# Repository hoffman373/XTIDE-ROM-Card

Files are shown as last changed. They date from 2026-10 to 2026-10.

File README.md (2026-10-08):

# XTIDE-ROM-Card

An 8-bit ISA card that holds a 27C256 EPROM as an option ROM in the upper memory area of a PC/XT-class machine, typically to load the [XTIDE Universal BIOS](https://www.xtideuniversalbios.org/).

The schematic is a redraw of Dan Hoover's "The $4 XTIDE" concept.

## Overview

- **ROM:** 27C256 (32 KB) EPROM in a 28-pin DIP socket
- **Address decode:** 74LS688 8-bit comparator in a 20-pin DIP socket
- **Address select:** 2x4 pin header (J1) with a SIP-5 pull-up resistor network (RN1)
- **Bus connector:** 8-bit ISA edge connector (`Bus_ISA_8bit`)
- **Decoupling:** 100 nF disc capacitors on each IC

### How it works

The 74LS688 compares A19-A15 against the levels set on J1. It also requires AEN low (no DMA cycle) and /MEMR low (memory read). When everything matches, it pulls `ROM_SEL` low and the EPROM drives D0-D7 for the read.

A19 is tied to match 1, so the 32 KB window always falls between 80000h and FFFFFh. RN1 pulls `SEL_A15` to `SEL_A18` high. Installing a jumper pulls that bit low.

### Address selection

| J1 pins | Address bit |
|---|---|
| 1-2 | A15 |
| 3-4 | A16 |
| 5-6 | A17 |
| 7-8 | A18 |

Jumper **in** = 0, jumper **out** = 1.

| ROM base | A18 | A17 | A16 | A15 | Jumpers installed |
|---|---|---|---|---|---|
| C8000h | 1 | 0 | 0 | 1 | 3-4, 5-6 |
| D0000h | 1 | 0 | 1 | 0 | 1-2, 5-6 |
| D8000h | 1 | 0 | 1 | 1 | 5-6 |
| E0000h | 1 | 1 | 0 | 0 | 1-2, 3-4 |
| E8000h | 1 | 1 | 0 | 1 | 3-4 |

- Keep the jumper off 7-8. A18 = 0 maps the ROM into A0000h-BFFFFh, which is video memory.
- C0000h is normally taken by the video BIOS.
- Pick a window that doesn't overlap video memory, a hard disk controller BIOS, or any other option ROM in the machine.

## Opening the project

1. Install [KiCad](https://www.kicad.org/) 10 or newer. The files use the KiCad 10 format and will not open in older versions.
2. Clone the repository:
   ```
   git clone https://github.com/hoffman373/XTIDE-ROM-Card.git
   ```
3. Open `xtide_rom_card.kicad_pro`.

Custom footprints live in `lib/footprints/` and are registered through the project's `fp-lib-table` using `${KIPRJMOD}`, so no library setup is needed. Everything else uses stock KiCad symbols and footprints.

## Programming the ROM

Burn the ROM image (for example, an XTIDE Universal BIOS build configured for your controller) to a 27C256 with any EPROM programmer. If the image is smaller than 32 KB, pad it to 32 KB with `FFh`. The BIOS checksum must be valid or the system BIOS will skip the ROM during its option ROM scan.

## License

CC BY-SA 4.0, share-alike with the original $4 XTIDE design.

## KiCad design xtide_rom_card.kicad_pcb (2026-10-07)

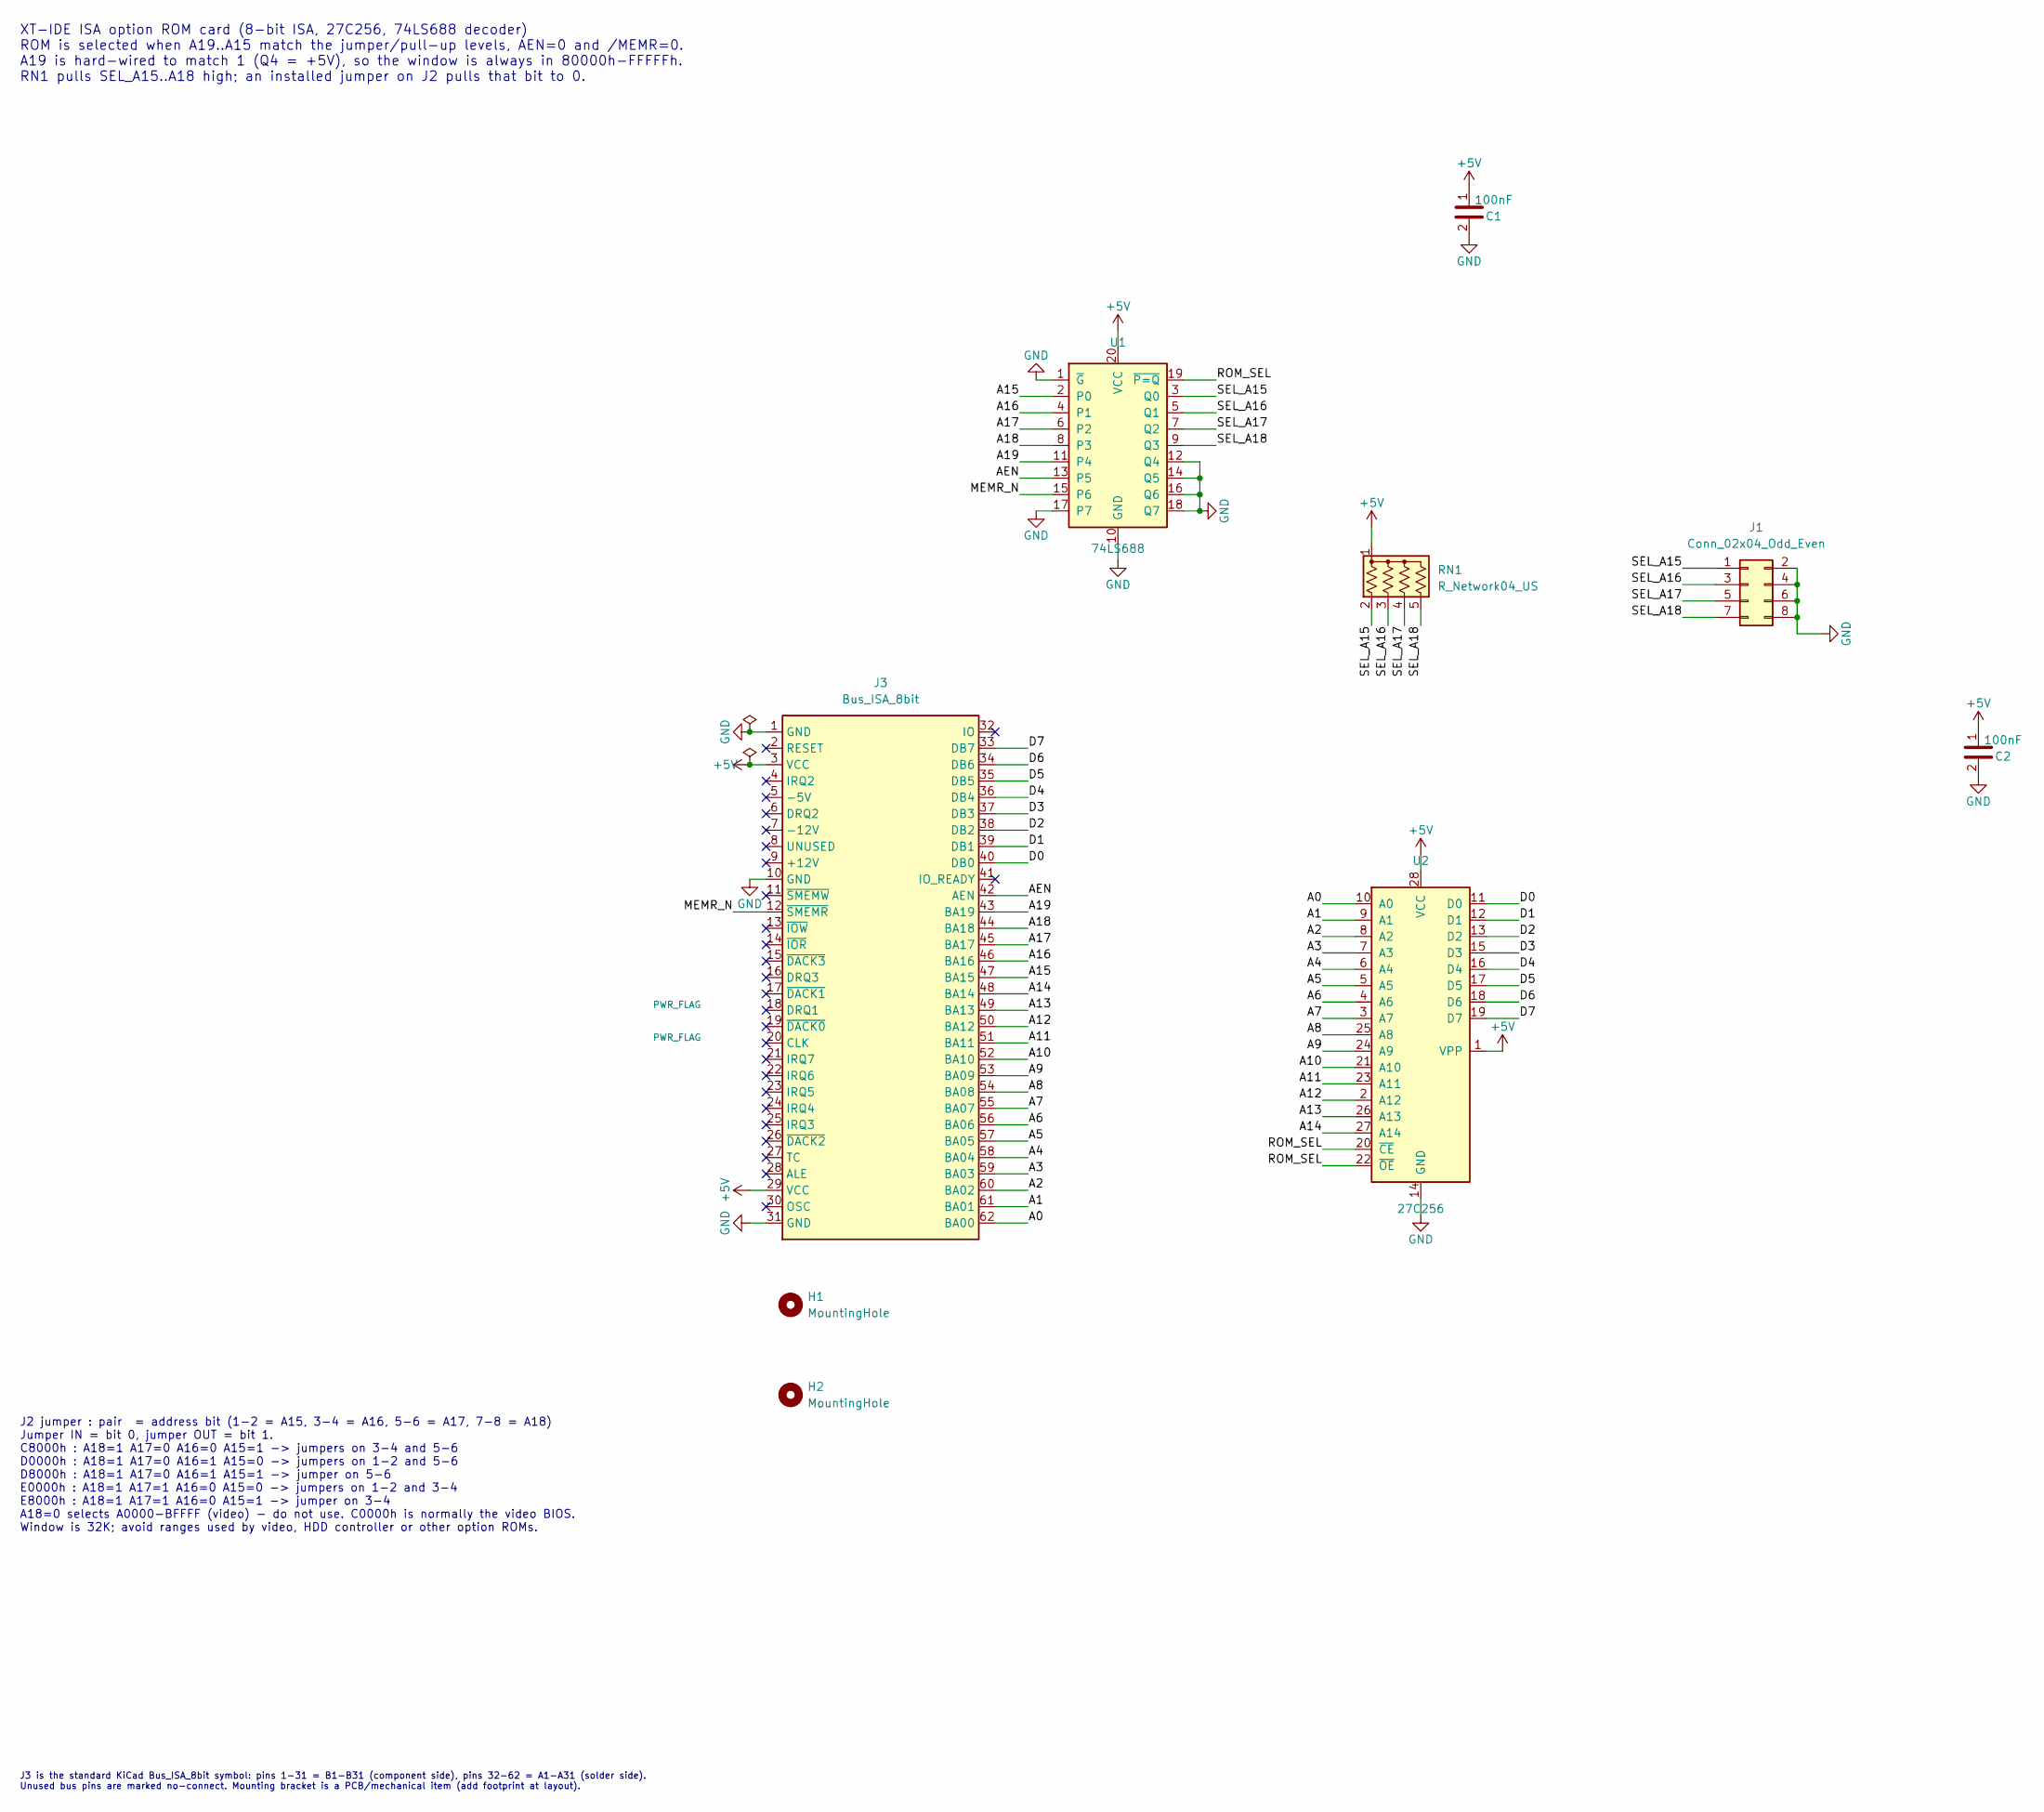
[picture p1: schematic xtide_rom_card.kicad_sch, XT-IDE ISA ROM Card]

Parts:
C1, C2: 100nF; C_Disc_D5.0mm_W2.5mm_P5.00mm
H1, H2: MountingHole; MountingHole_3.2mm_M3
J1: Conn_02x04_Odd_Even; PinHeader_2x04_P2.54mm_Vertical
J3: Bus_ISA_8bit; PC_AT_8BIT
RN1: R_Network04_US; R_Array_SIP5
U1: 74LS688; DIP-20_W7.62mm_Socket
U2: 27C256; DIP-28_W15.24mm_Socket

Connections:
+5V: C1.1, C2.1, J3.3 (VCC), J3.29 (VCC), RN1.1 (common), U1.20 (VCC), U2.1 (VPP), U2.28 (VCC)
/A0: J3.62 (BA00), U2.10 (A0)
/A1: J3.61 (BA01), U2.9 (A1)
/A2: J3.60 (BA02), U2.8 (A2)
/A3: J3.59 (BA03), U2.7 (A3)
/A4: J3.58 (BA04), U2.6 (A4)
/A5: J3.57 (BA05), U2.5 (A5)
/A6: J3.56 (BA06), U2.4 (A6)
/A7: J3.55 (BA07), U2.3 (A7)
/A8: J3.54 (BA08), U2.25 (A8)
/A9: J3.53 (BA09), U2.24 (A9)
/A10: J3.52 (BA10), U2.21 (A10)
/A11: J3.51 (BA11), U2.23 (A11)
/A12: J3.50 (BA12), U2.2 (A12)
/A13: J3.49 (BA13), U2.26 (A13)
/A14: J3.48 (BA14), U2.27 (A14)
/A15: J3.47 (BA15), U1.2 (P0)
/A16: J3.46 (BA16), U1.4 (P1)
/A17: J3.45 (BA17), U1.6 (P2)
/A18: J3.44 (BA18), U1.8 (P3)
/A19: J3.43 (BA19), U1.11 (P4)
/AEN: J3.42 (AEN), U1.13 (P5)
/D0: J3.40 (DB0), U2.11 (D0)
/D1: J3.39 (DB1), U2.12 (D1)
/D2: J3.38 (DB2), U2.13 (D2)
/D3: J3.37 (DB3), U2.15 (D3)
/D4: J3.36 (DB4), U2.16 (D4)
/D5: J3.35 (DB5), U2.17 (D5)
/D6: J3.34 (DB6), U2.18 (D6)
/D7: J3.33 (DB7), U2.19 (D7)
/MEMR_N: J3.12 (~SMEMR), U1.15 (P6)
/ROM_SEL: U1.19 (~P=Q), U2.20 (~CE), U2.22 (~OE)
/SEL_A15: J1.1, RN1.2 (R1), U1.3 (Q0)
/SEL_A16: J1.3, RN1.3 (R2), U1.5 (Q1)
/SEL_A17: J1.5, RN1.4 (R3), U1.7 (Q2)
/SEL_A18: J1.7, RN1.5 (R4), U1.9 (Q3)
GND: C1.2, C2.2, J1.2, J1.4, J1.6, J1.8, J3.1 (GND), J3.10 (GND), J3.31 (GND), U1.1 (~G), U1.10 (GND), U1.12 (Q4), U1.14 (Q5), U1.16 (Q6), U1.17 (P7), U1.18 (Q7), U2.14 (GND)

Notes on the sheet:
J3 is the standard KiCad Bus_ISA_8bit symbol: pins 1-31 = B1-B31 (component side), pins 32-62 = A1-A31 (solder side). Unused bus pins are marked no-connect. Mounting bracket is a PCB/mechanical item (add footprint at layout).
J2 jumper : pair = address bit (1-2 = A15, 3-4 = A16, 5-6 = A17, 7-8 = A18) Jumper IN = bit 0, jumper OUT = bit 1. C8000h : A18=1 A17=0 A16=0 A15=1 -> jumpers on 3-4 and 5-6 D0000h : A18=1 A17=0 A16=1 A15=0 -> jumpers on 1-2 and 5-6 D8000h : A18=1 A17=0 A16=1 A15=1 -> jumper on 5-6 E0000h : A18=1 A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
XT-IDE ISA option ROM card (8-bit ISA, 27C256, 74LS688 decoder) ROM is selected when A19..A15 match the jumper/pull-up levels, AEN=0 and /MEMR=0. A19 is hard-wired to match 1 (Q4 = +5V), so the window is always in 80000h-FFFFFh. RN1 pulls SEL_A15..A18 high; an installed jumper on J2 pulls that bit 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

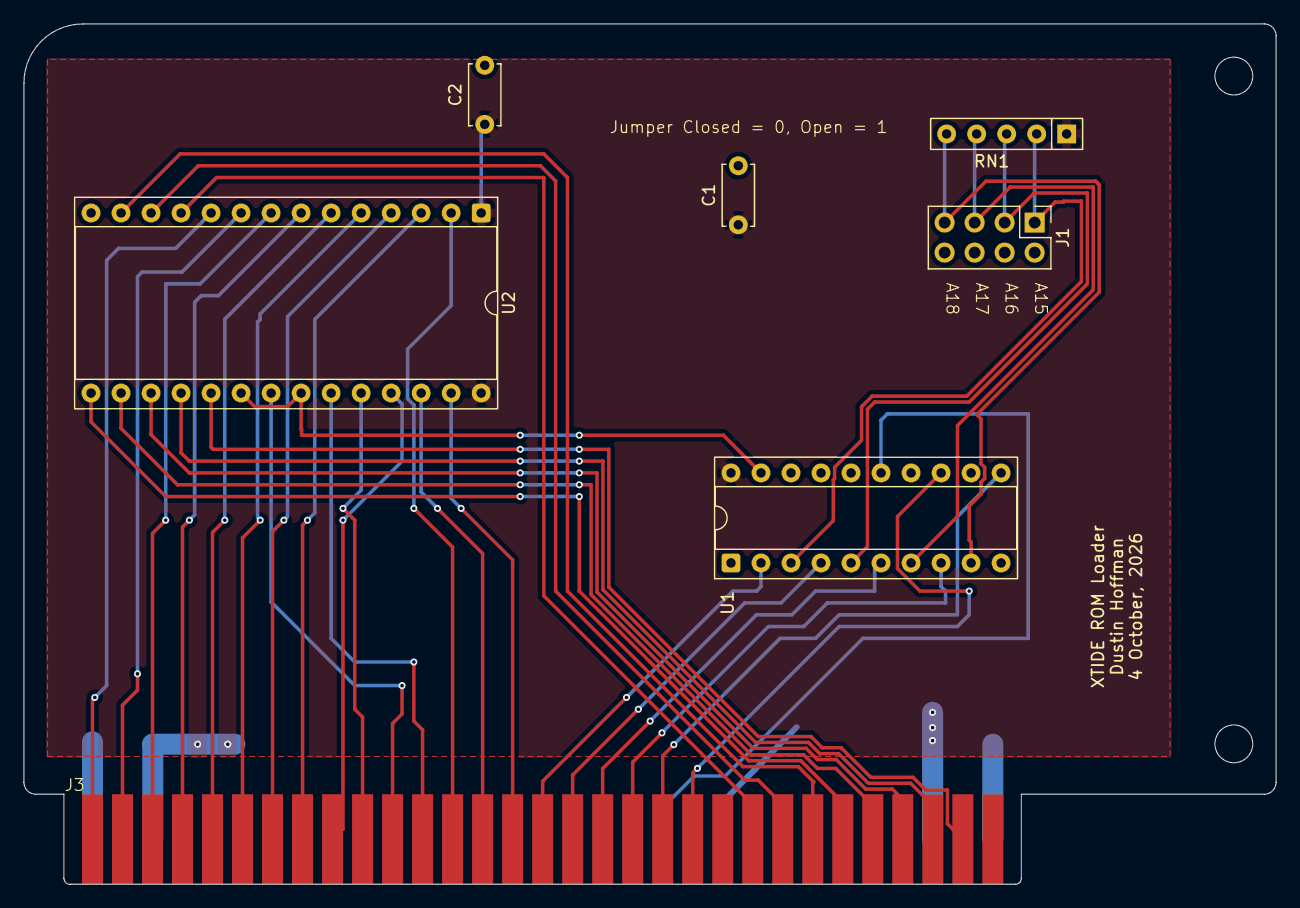
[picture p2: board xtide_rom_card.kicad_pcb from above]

Board: 2 copper layers, 106.0 x 72.8 mm, 9 parts (0 on the bottom side), 37 nets.

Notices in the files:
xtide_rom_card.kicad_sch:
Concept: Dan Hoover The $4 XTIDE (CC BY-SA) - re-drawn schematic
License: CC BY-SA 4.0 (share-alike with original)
